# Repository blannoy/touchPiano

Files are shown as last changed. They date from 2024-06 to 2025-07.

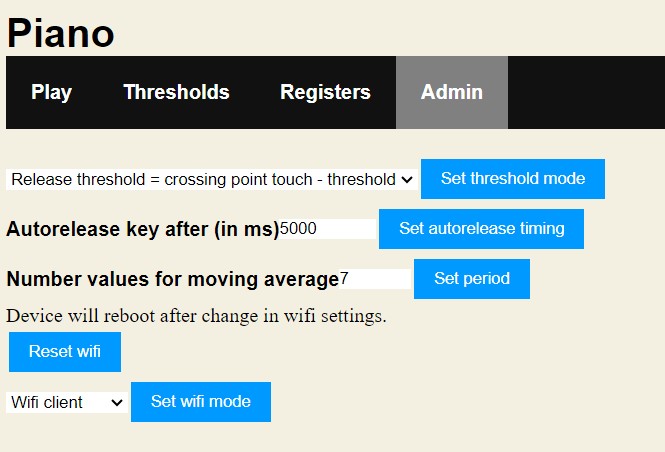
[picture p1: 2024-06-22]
screenshots/admin.jpg

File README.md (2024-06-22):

# Touch-based floor piano

This project contains the source code to drive a MPR121 & Nodemcu based "floor piano". Wearing socks you should be able to generate key-presses. 

The sound is played by a connected computer within a browser. 



## Components & material

### Electronics

- NodeMCU ESP8266
- 2x [Adafruit MPR121](https://www.adafruit.com/product/1982) -> 12 pins each = 24 keys
  The system is powered via NodeMCU USB port. The setup was put together on a prototype board.



> Warning: powering the NodeMCU with a battery is preferred. Using a laptop or USB charger can lead to noise which may trigger a 'hit'.

### Physical world

The piano was built using aluminium foil glued to cardboard and covered with a sheet of tissue paper.
A piece of [copper tape with conductive adhesive](https://www.adafruit.com/product/3483) was fixed on the foil. This makes it easy to solder a wire to the foil.
Do this for each piece of the piano (e.g. 24 keys) or other layout you wish to use.
Each wire needs to be connected to a pin of the MPR121.



## Software

### Setup

The software was developed using Visual Studio Code combined with PlatformIO.

> Disclaimer: I'm not a professional developer/web designer

There are 2 main parts: the firmware and a React based front-end.

Folder layout:

- `/src`: firmware source code
- `/web/src`: web front end source code
- `/config`: location for config.json that will be copied during build of the website
- `/data`: folder for NodeMCU image files
- `/instruments`: folder with `instruments.json`, that contains possible instruments. These were obtained from [here](https://github.com/gleitz/midi-js-soundfonts/). You will need to get them yourself as they are not included in the project.

### Firmware

The NodeMCU firmware contains a REST API that can be used to:

- start/stop the MPR121
- stream JSON data (using Server Sent Events, SSE) to listening clients. Depending on the API endpoint, the stream contains for each pin the (raw) sensor data, a running average, a hit signal and a hit state
- modify different parameters of the software / sensor registers
  The main configuration is stored on the board in a JSON file.

A sample JSON configuration is in the /config folder. This file is copied during the image-build of the web site. It contains the register values for the sensors, threshold values for touch/release, moving average period, wifi mode and threshold mode.

The **threshold** can be used in two modes, of which CROSS seemed to work the best.

- `CROSS`: when the signal goes below the threshold, the release threshold is set at 85% of the difference between average and the current value
- `STANDARD`: fixed values of touch and release threshold relative to the moving average

**Wifi** mode: WifiManager is used to connect the NodeMCU to an existing Wifi network. On first load an AP will be available to configure the client. After that you can choose to use the existing wifi network (CLIENT) or let the NodeMCU setup its own AP (mode AP) where you will need to provide a password (via the web interface).

### Web front end

A React frontend is used to control the sensor and readout the different JSON-streams. The source code is in `web/src`.

You chould be familiar with building and serving a React-based website.

The menu (see screenshots in [/screenshots](screenshots/) contains:

- `Play`: a rendition of a piano, selection of instrument and buttons to start the piano with or without sound. The state of the key is also shown.
- `Thresholds`: set and visualize the thresholds and hits. Easy to setup the piano and debug its sensitivity.
- `Registers`: an interface to set and visualize the impact of setting different registers of the MPR121.
- `Admin`: set some additional parameters. These are the wifi mode, threshold mode, a delay to perform an autolrelease of a key, the moving average period (number of values to average)

The front-end can be run in different setups. The .env.* files are used to set some variables. Main variables are REACT_APP_BASE_URL (where is the firmware API endpoint) and REACT_APP_SOUND_URL (where are the instruments).

Building the React app can be done in 2 modes:

- `image`: the site is built and stored in /data. This needs to be uploaded to to the nodeMCU. Due to the size of the instrument files, these will be fetched over the internet when running the site in a browser.
- `local`: site is built in /web/build containing the instrument files that are present in /instruments.

When running the site on your machine, you can choose to:

- `start`: the site is run in development mode. Instrument files are fetched over the internet.
- `local`: the site runs in production mode. The instrument-files are locally stored. This allows you to run the NodeMCU as a separate WIFI access point an connect directly to it.
  There are some scripts in `scripts/` to help you.

# Getting up and running

- Build your physical sensors
- Wire up everything
- Make sure the correct IP-addresses are in the different .env.* files
- Download some instrument files and add them to the instruments/instruments.json
- Compile and upload the firmware with PlatformIO/ArduinoIDE/...
- A pre-built site is in this github. The local-built version assumes a NodeMCU at 192.168.0.38. If you cannot use them, you will need to build the website using the build-script in scripts/. `build.cmd image` and `build.cmd local`.
- Upload the image to the NodeMCU using PlatformIO/ArduinoIDE/...
- You should be able to connect to the NodeMCU and see the website
- Running the website on a local PC using `start.cmd local`

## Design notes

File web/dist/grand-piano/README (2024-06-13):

The folder samples should contain the ogg / m4a files from https://github.com/smpldsnds/sfzinstruments-splendid-grand-piano
Replace the space by -, e.g. "FF A#2.m4a" should be "FF-A#2.m4a"

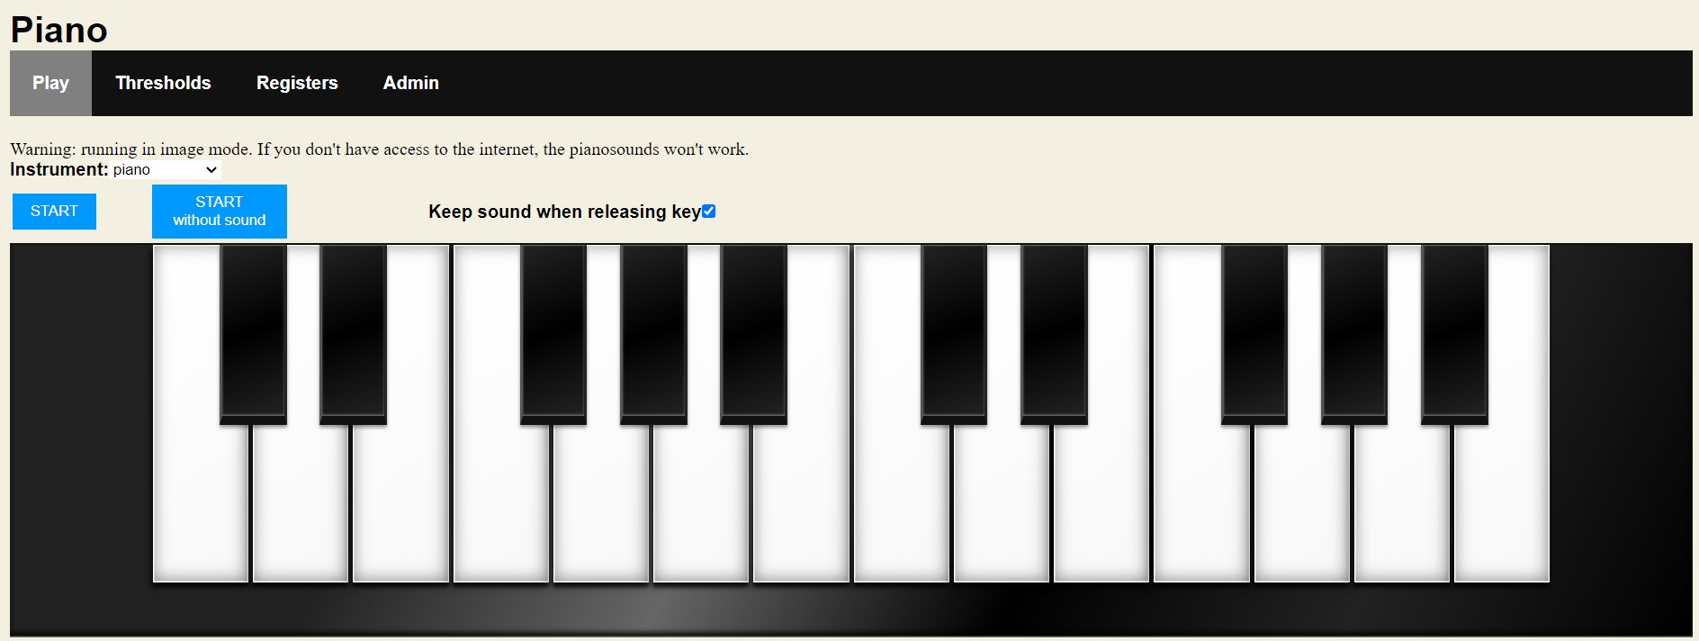
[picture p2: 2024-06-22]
screenshots/piano_off.jpg

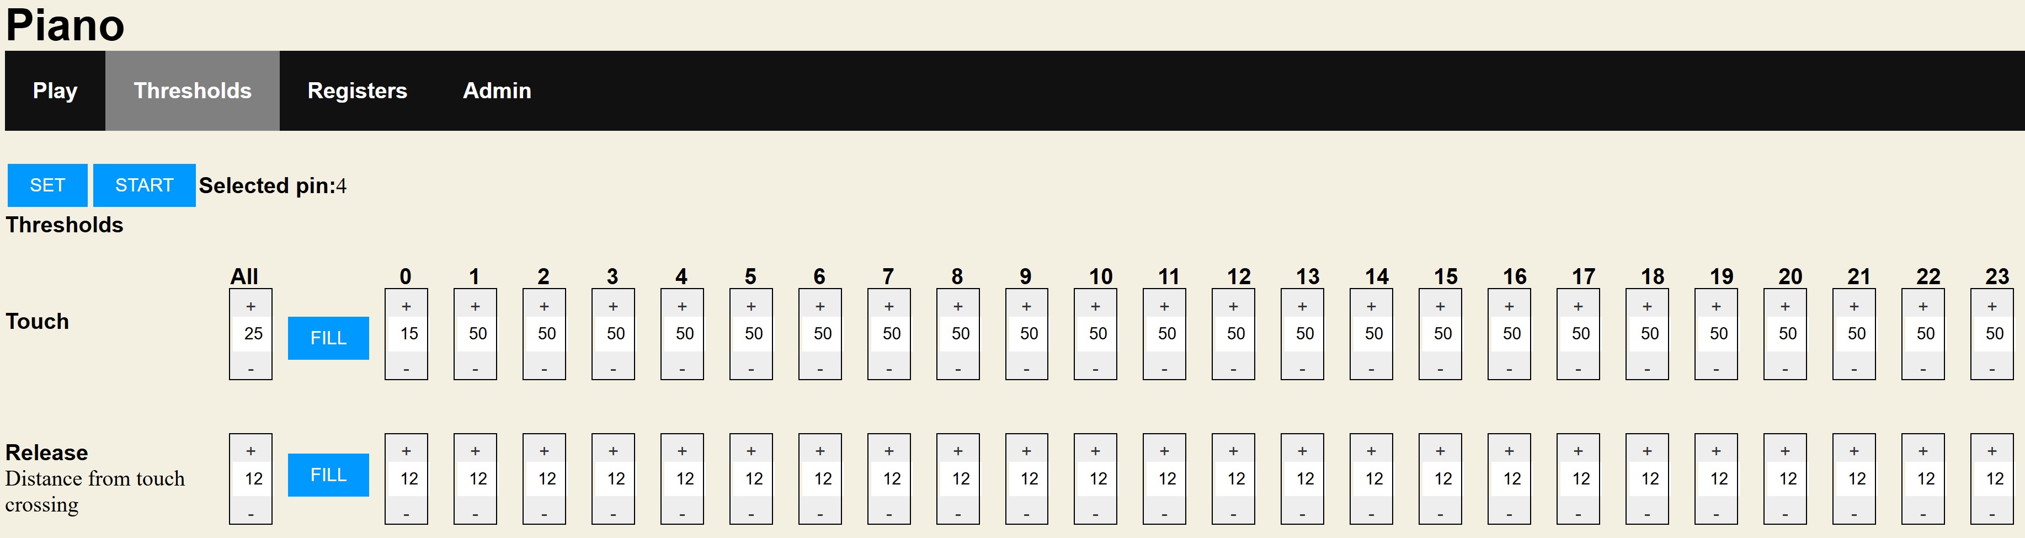
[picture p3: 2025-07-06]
screenshots/thresholds_off.jpg

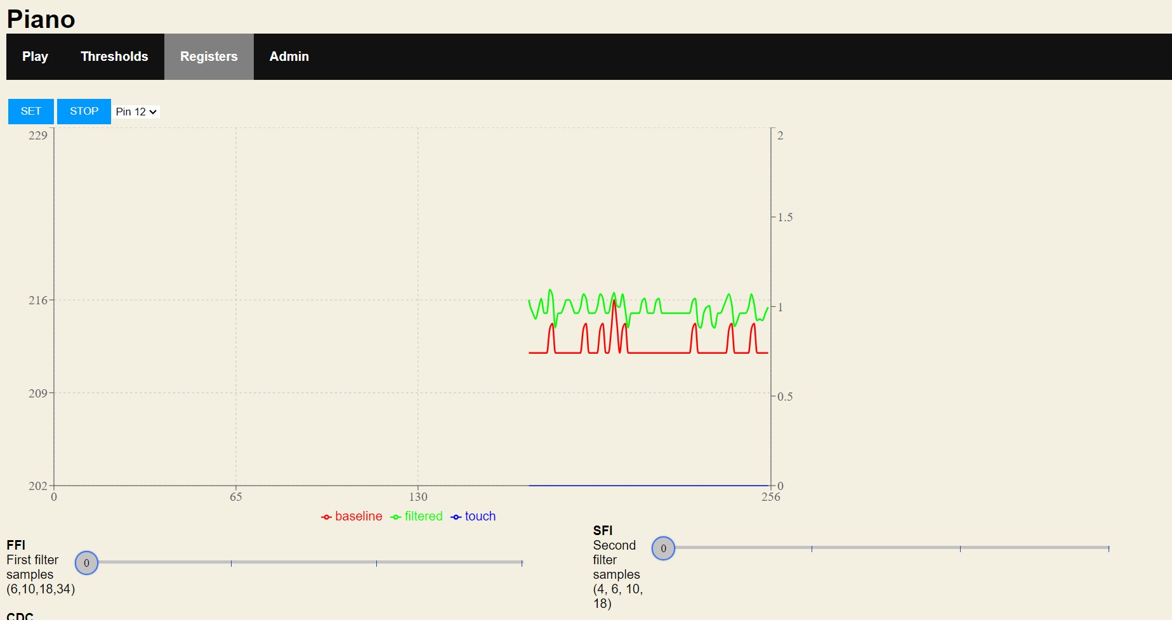
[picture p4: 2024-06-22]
screenshots/registers_on.jpg

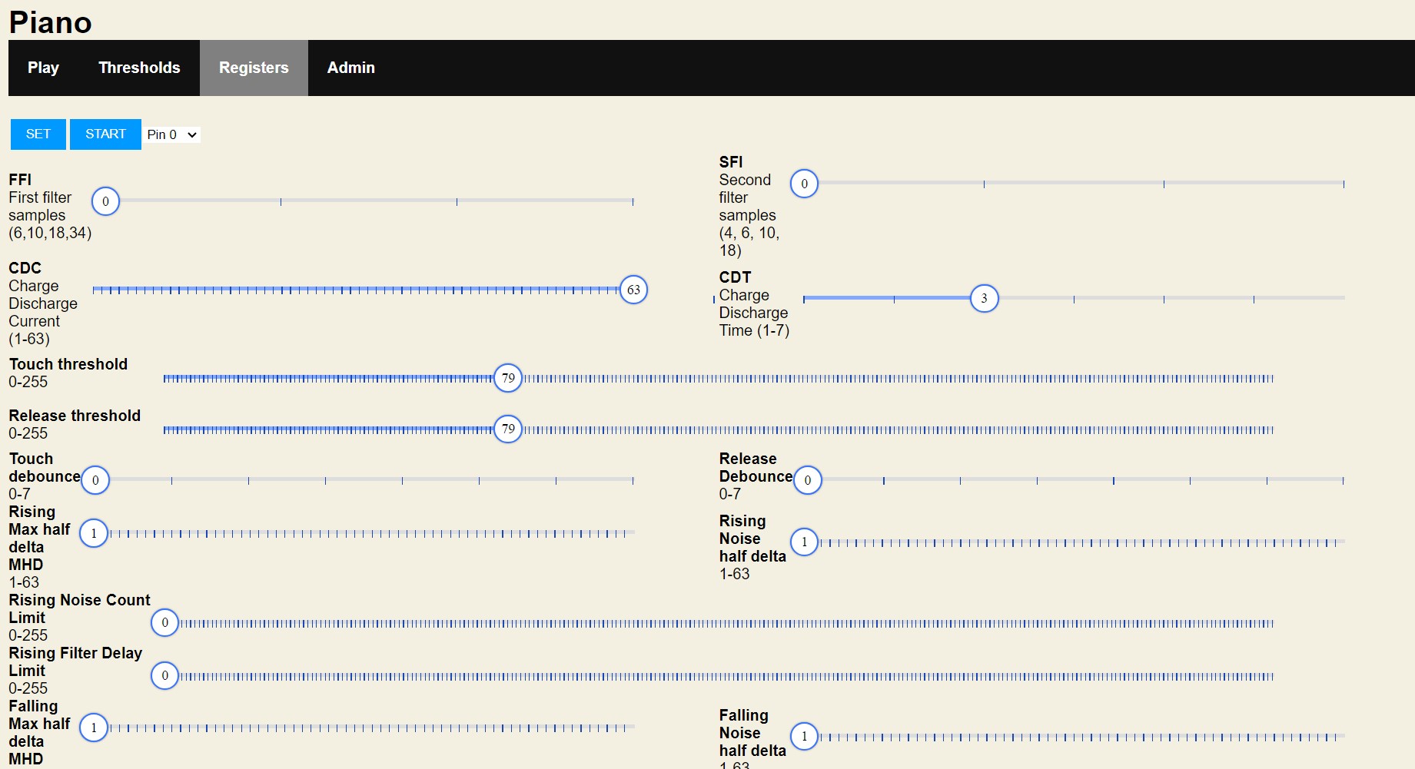
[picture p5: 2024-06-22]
screenshots/registers_off.jpg

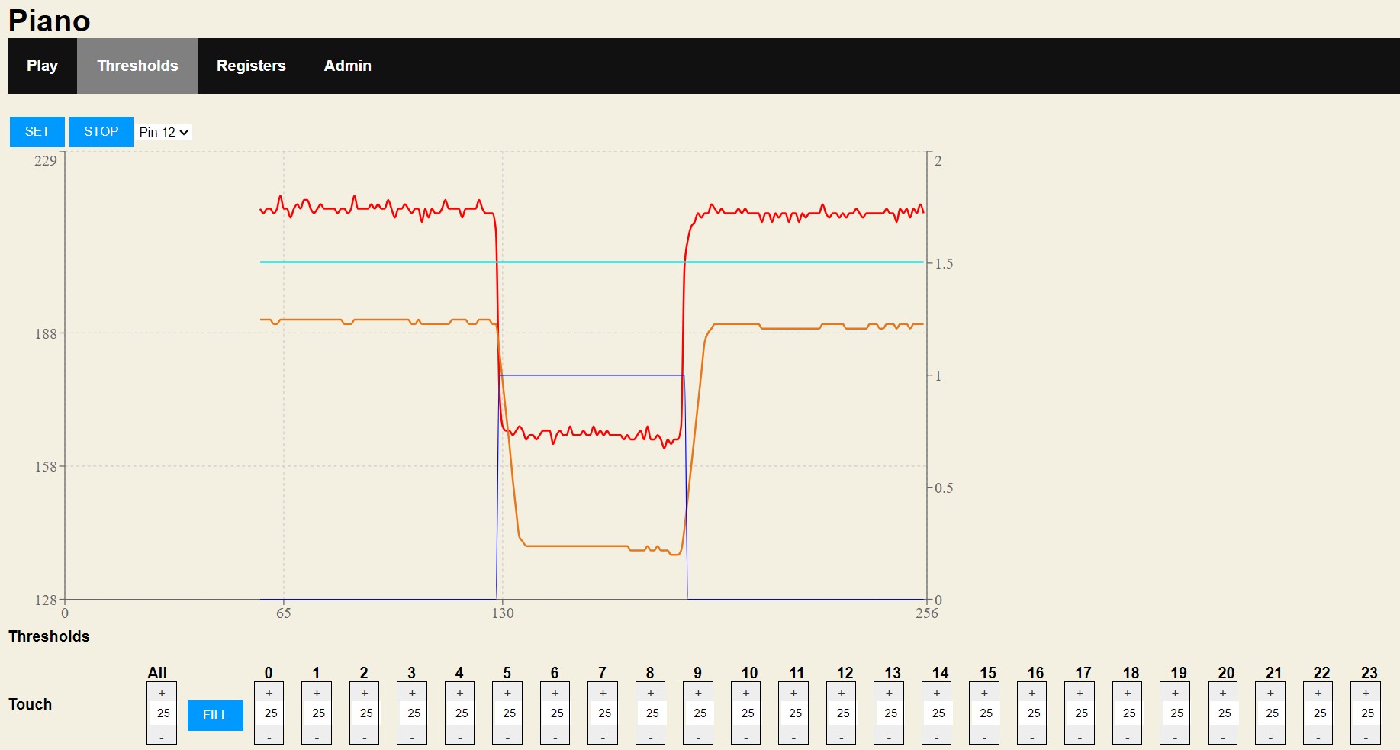
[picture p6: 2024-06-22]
screenshots/thresholds_on.jpg

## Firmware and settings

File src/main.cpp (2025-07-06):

#include <Arduino.h>
#define DEBUG true
// #include <ESP8266WiFi.h>
// #include <WiFiClient.h>
// #include <ESP8266WebServer.h>
// #include <ESP8266WiFi.h>
// #define WIFIAP
const char *ssid = "touchPiano-AP";
#define MAXREADINGS 20
#include <headers.h>
#include <configuration.h>
#ifdef ESP32
#include <WiFi.h>
#include <AsyncTCP.h>
#elif defined(ESP8266)
#include <ESP8266WiFi.h>
#include <ESPAsyncTCP.h>
#endif
#define WEBSERVER_H "fix confict"
#include <WiFiManager.h>
#include <ESPAsyncWebServer.h>
#include <ESP8266mDNS.h>
#include <Adafruit_MPR121.h>

AsyncWebServer server(80);
void webServerSetup();
void stopServer();

#include "wifi.h"
#include "webserver.h"
#define filesystem (LittleFS)


Adafruit_MPR121 cap[NUMSENSORS];

// Keeps track of the last pins touched
// so we know when buttons are 'released'
uint16_t lastTouched[NUMSENSORS];
uint16_t currTouched[NUMSENSORS];
uint16_t avgCurrTouched[NUMSENSORS];
uint16_t avgLastTouched[NUMSENSORS];
RunningAverage averagedData[NUMKEYS];
uint16_t thresholdCrossed[NUMSENSORS][NUMKEYS / 2];
long autoReleaseTimer[NUMKEYS];

uint8_t sensorAddress[] = {0x5A, 0x5B};

void sensorSetup()
{
  for (int i = 0; i < NUMSENSORS; i++)
  {
    cap[i] = Adafruit_MPR121();
  }
}

void setup()
{
  Serial.begin(115200);
  filesystem.begin();
  loadConfiguration(&config);
  dumpLittleFS();
  sensorSetup();
  wifiSetup();
  webServerSetup();

  pinMode(LED_BUILTIN, OUTPUT);
  digitalWrite(LED_BUILTIN, HIGH);

}

void sensorLoop()
{
  JsonDocument doc;
  JsonArray keyState = doc["keyState"].to<JsonArray>();
  JsonArray keyHit = doc["keyHit"].to<JsonArray>();
  JsonArray filteredDataArray = doc["filtered"].to<JsonArray>();
  JsonArray averagedDataArray = doc["averaged"].to<JsonArray>();
  JsonArray baselineDataArray = doc["baseline"].to<JsonArray>();
  JsonArray releaseDataArray = doc["release"].to<JsonArray>();
  bool sendPianoEvent = false;
  bool sendHit = false;
  bool keepHit = false;
  for (int sensorNr = 0; sensorNr < NUMSENSORS; sensorNr++)
  {
    currTouched[sensorNr] = cap[sensorNr].touched();

    for (uint8_t i = 0; i < 12; i++)
    {
      int keyNr = sensorNr * (NUMKEYS / NUMSENSORS) + i;
      long value = cap[sensorNr].filteredData(i);
      long currentAvg = averagedData[keyNr].getAverage(value);
      if (((currentAvg - value) > config.customTouchThreshold[keyNr]) && !(bitRead(avgCurrTouched[sensorNr],i)>0))
      {
        bitSet(avgCurrTouched[sensorNr], i);
        thresholdCrossed[sensorNr][i] = value + (currentAvg - value) * 0.85;
        autoReleaseTimer[sensorNr] = millis();
      }
      else if (bitRead(avgCurrTouched[sensorNr],i)>0)
      {
        switch (config.thresholdMode)
        {
        case STANDARD:
          if ((value - currentAvg) > config.customReleaseThreshold[keyNr])
          {
            bitClear(avgCurrTouched[sensorNr], i);
          }
          break;
        case CROSS:
          if (value > (thresholdCrossed[sensorNr][i] - config.customReleaseThreshold[keyNr]))
          {
            bitClear(avgCurrTouched[sensorNr], i);
          }
          break;
        default:
          break;
        }
        // autorelease after autorelease timer
        if ((millis() - autoReleaseTimer[sensorNr]) > config.autoRelease)
        {
          bitClear(avgCurrTouched[sensorNr], i);
        }
      }

      if (runMode == "calibrate")
      {
        filteredDataArray[keyNr] = value;
        baselineDataArray[keyNr] = cap[sensorNr].baselineData(i);
        keyState[keyNr] = (bitRead(currTouched[sensorNr],i)>0);
      }
      else if (runMode == "thresholds")
      {
        filteredDataArray[keyNr] = value;
        averagedDataArray[keyNr] = currentAvg;
        releaseDataArray[keyNr] = thresholdCrossed[sensorNr][i] - config.customReleaseThreshold[keyNr];
        keyState[keyNr] = (bitRead(avgCurrTouched[sensorNr], i)>0);
        keyHit[keyNr] = (bitRead(avgCurrTouched[sensorNr] ,i)>0) && !(bitRead(avgLastTouched[sensorNr],i)>0);
      }
      else if (runMode == "piano")
      {
        keyState[keyNr] = (bitRead(avgCurrTouched[sensorNr], i)>0);
        bool isHit = ( (bitRead(avgCurrTouched[sensorNr] ,i)>0) && !(bitRead(avgLastTouched[sensorNr],i)>0));
        keyHit[keyNr] = isHit;
        if (isHit)
          sendHit = true;
      }
      if (keyState[keyNr] > 0)
        keepHit = true;
    }
    if (keepHit)
    {
      digitalWrite(LED_BUILTIN, HIGH);
    }
    else
    {
      digitalWrite(LED_BUILTIN, LOW);
    }
    if (avgLastTouched[sensorNr] != avgCurrTouched[sensorNr])
    {
      sendPianoEvent = true;
    }
    lastTouched[sensorNr] = currTouched[sensorNr];
    avgLastTouched[sensorNr] = avgCurrTouched[sensorNr];
  }
  doc["clock"] = millis();

  String message = "";
  serializeJson(doc, message);

  if (runMode == "calibrate")
  {
    calibrationEvents.send(message.c_str(), "message", millis());
  }
  else if (runMode == "thresholds")
  {
    thresholdEvents.send(message.c_str(), "message", millis());
  }
  else if (runMode == "piano")
  {
    if (sendPianoEvent)
    {
      pianoEvents.send(message.c_str(), "message", millis());
      // empty event for python sse-client to fire
      //   pianoEvents.send("", "message", millis());
      if (sendHit)
      {
        Serial.print("pianoHit:");
        serializeJson(doc["keyHit"], Serial);
        Serial.println();
      }
    }
  }
}

void loop()
{
  // Get the currently touched pads
  // wifiLoop();
  if (serverStarted)
  {
    webServerLoop();
  }
  if (startSensor && !sensorStarted)
  {
    for (int sensorNr = 0; sensorNr < NUMSENSORS; sensorNr++)
    {
      if (!cap[sensorNr].begin(sensorAddress[sensorNr]))
      {
        Serial.printf("MPR121 %04X not found, check wiring?\n", sensorAddress[sensorNr]);
        while (1)
          ;
      }

      byte newAFE_Reg = (config.FFI << 6) | config.CDC;
      byte FCR_Reg = cap[sensorNr].readRegister8(MPR121_CONFIG2);
      byte ESI = (FCR_Reg & 0b00000111);
      byte newFCR_Reg = (config.CDT << 5) | (config.SFI << 3) | ESI;
      // byte debounce_Reg = cap[sensorNr].readRegister8(MPR121_DEBOUNCE);
      byte newDebounce_Reg = (config.touchDebounce << 4) | config.releaseDebounce;

      byte ECR_Reg = cap[sensorNr].readRegister8(MPR121_ECR);

      cap[sensorNr].writeRegister(MPR121_ECR, 0x0); // go to STOP Mode
      cap[sensorNr].writeRegister(MPR121_CONFIG1, newAFE_Reg);
      cap[sensorNr].writeRegister(MPR121_CONFIG2, newFCR_Reg);
      cap[sensorNr].setThresholds(config.touchThreshold, config.releaseThreshold);
      cap[sensorNr].writeRegister(MPR121_DEBOUNCE, newDebounce_Reg);
      cap[sensorNr].writeRegister(MPR121_MHDR, config.MHD[0]);
      cap[sensorNr].writeRegister(MPR121_NHDR, config.NHD[0]);
      cap[sensorNr].writeRegister(MPR121_NCLR, config.NCL[0]);
      cap[sensorNr].writeRegister(MPR121_FDLR, config.FDL[0]);
      cap[sensorNr].writeRegister(MPR121_MHDF, config.MHD[0]);
      cap[sensorNr].writeRegister(MPR121_NHDF, config.NHD[0]);
      cap[sensorNr].writeRegister(MPR121_NCLF, config.NCL[0]);
      cap[sensorNr].writeRegister(MPR121_FDLF, config.FDL[0]);
  for (int iLoop=0;iLoop<NUMKEYS;iLoop++){
    averagedData[iLoop].numReadings=config.averagePeriod;
  }
      cap[sensorNr].writeRegister(MPR121_ECR, ECR_Reg); // exit stop mode
    }
    startTime = millis();
    sensorStarted = true;
    Serial.printf("Started in mode %s\n", runMode);
  }
  else if (!startSensor && sensorStarted)
  {
    for (int sensorNr = 0; sensorNr < NUMSENSORS; sensorNr++)
    {
      cap[sensorNr].writeRegister(MPR121_ECR, 0x0); // go to STOP Mode
      avgLastTouched[sensorNr] = 0;
      avgCurrTouched[sensorNr] = 0;
    }
    sensorStarted = false;
    digitalWrite(LED_BUILTIN, HIGH);
    Serial.printf("Stopped in mode %s\n", runMode);
  }

  if (sensorStarted)
  {
    sensorLoop();
  }
  if (runMode == "piano")
  {
    delay(10);
  }
  else
  {
    delay(50);
  }
}

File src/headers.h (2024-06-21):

#pragma once
#include <Arduino.h>
#include <ArduinoJson.h>
#include <utils.h>
#include <FS.h>
#include <LittleFS.h>
#define MAXPWSIZE 30
#define filesystem (LittleFS)
String runMode;

typedef enum { CLIENT, AP} WifiMode;
String wifiModeString[2] = {"CLIENT", "AP"};

// Threshold modes
// STANDARD: "release" determined by increase amount of releaseThreshold above current average 
// CROSS: "release" determined by crossing the point where touch was detected - releaseThreshold 
typedef enum { STANDARD, CROSS } ThresholdMode;
String thresholdModeString[2] = {"STANDARD", "CROSS"};
#define NUMKEYS 24
#define NUMSENSORS 2
struct Configuration
{
    int customTouchThreshold[NUMKEYS];
    int customReleaseThreshold[NUMKEYS];
    byte FFI = 0, CDC = 63; // AFE register MPR121_CONFIG1 XXYYYYYY
    byte CDT = 5, SFI = 0;  // FRC register MPR121_CONFIG2 XXXYYZZZ
    byte touchThreshold = 9, releaseThreshold = 6;
    byte touchDebounce = 0, releaseDebounce = 0; // Debounce register MPR121_DEBOUNCE 0-7 : XTTTXRRR
    byte MHD[2], NHD[2], NCL[2], FDL[2];
    WifiMode wifiMode;
    ThresholdMode thresholdMode=CROSS;
    int autoRelease=15000;
    int averagePeriod=5;
    char apPW[MAXPWSIZE]="calibMpr121";
};

Configuration config;

#define NUMCONFKEYS 12
String configKeys[NUMCONFKEYS] = {"customTouchThreshold", "customReleaseThreshold", "FFI", "CDC", "CDT", "SFI", "touchThreshold", "touchDebounce","releaseThreshold", "releaseDebounce", "Rising", "Falling"};



bool wifiConnected = false;
bool serverStarted = false;
bool startSensor = false;
bool sensorStarted = false;
bool calibrationMode = false;
long startTime;

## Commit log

2024-06-13 first working version
    [configuration.h]
2025-07-06 Change in threshold visualization and minor fixes
    [piano.fzz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]
